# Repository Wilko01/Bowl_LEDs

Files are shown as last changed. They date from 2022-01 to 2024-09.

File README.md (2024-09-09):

# Bowl with LEDS
Control the intensity of the LEDS via a NODEMCU with PWM and add it to Home Assistant

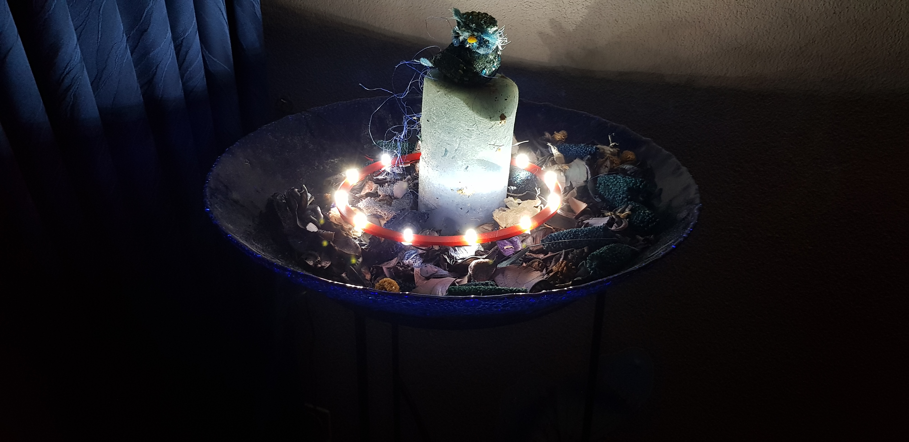
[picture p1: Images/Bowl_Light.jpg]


## Description and operation instructions
12Leds controlled via a dashboard in Home Assistant.

 ## Technical description
Calculate the value of the resistor in relation to the amount of LEDs. In this case 12 LEDs will be used with a forward voltage of 3.2 - 3.4V and a forward current of 20mA. 5V will be used as input as that is minimal required for the NodeMCU and can be powered via an USB charger.
The LEDs will be connected in parallel leaving the voltage over the resistor 5V - 3.3V = 1.7V. Take 12 LEDs multiplied by 20mA = max 240mA. The resistor will then be 1.7V / 240mA = ~8hm. As I did not have a 8 Ohm 0,5W I used a 12 Ohm 0,5W resistor. This also ensures that we are not operating at the edge. A BD139 is used as it needs to deal with 240mA where a BD547C can only deliver 100mA max.
Don't use D4 as it will give issues during boot. Use D5 of the NodeMCU instead.

### Parts
- 1 x NodeMCU

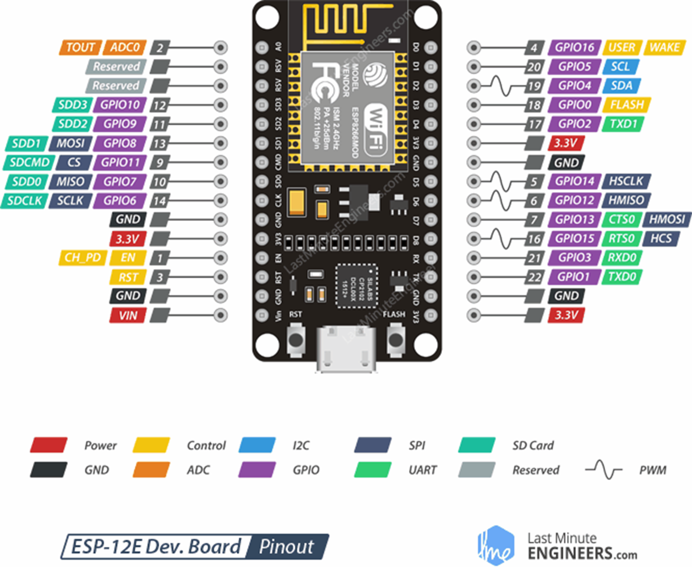
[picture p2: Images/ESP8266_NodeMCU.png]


- 12 x 5mm white led
- 1 x 12 Ohm 0,5W resistor
- 1 x 1k resistor
- 1 x BD139 NPN transistor
- 1 x JST 2.54 2 pin connector

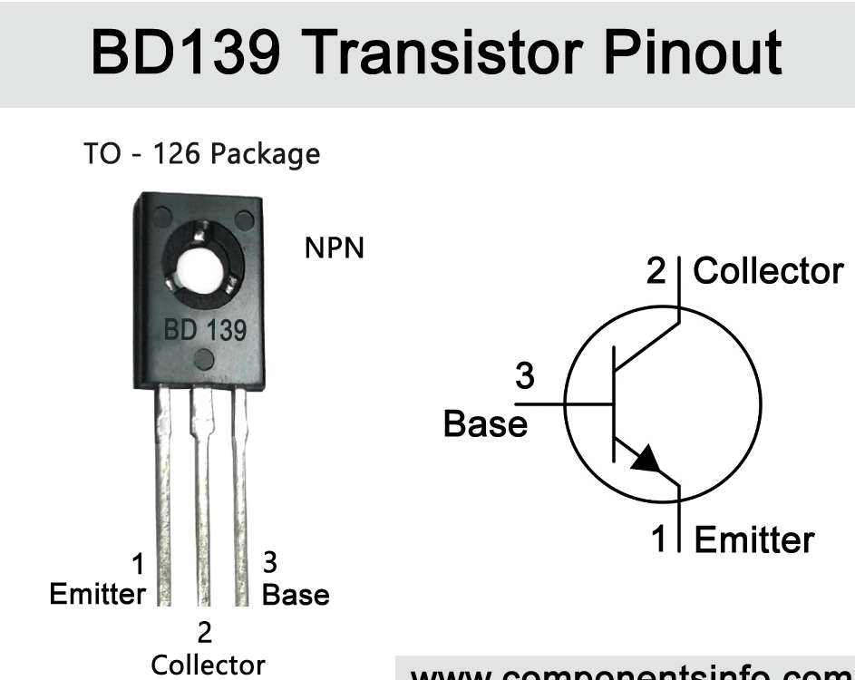
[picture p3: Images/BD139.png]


### Schematic overview
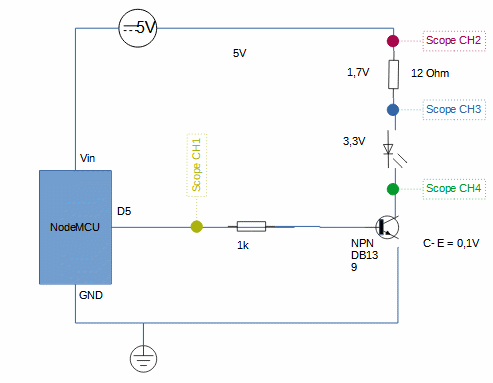
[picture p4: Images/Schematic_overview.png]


### ESPHome installation
See the instructions https://github.com/Wilko01/ESPHome  (not listed here)

### ESPHome Configuration in Home Assistant
Create a new device  with this code:
```
#Running via ESPHOME

#Runs on a NodeMCU

esphome:
  name: bowl-lamp

esp8266:
  board: nodemcuv2

# Enable logging
logger:

# Enable Home Assistant API
api:

ota:
  platform: esphome
  password: "1e7c9c2b1830d88364f40572c813b20f"

wifi:
  ssid: !secret wifi_ssid
  password: !secret wifi_password

  # Enable fallback hotspot (captive portal) in case wifi connection fails
  ap:
    ssid: "Bowl-Leds Fallback Hotspot"
    password: "7lgvJ8aOzZ3w"

captive_portal:

# Add virtual switch to remotely restart the ESP via HA
# https://esphome.io/components/switch/restart
button:
  - platform: restart
    name: "ESP_bowl-leds restart"

#begin code

output:
  - platform: esp8266_pwm
    pin: D5
    frequency: 1000 Hz
    id: pwm_output

fan:
  - platform: speed
    output: pwm_output
    name: "Bowl-Lamp"
#end code
```

### Interface
#### Home Assistant
Home Assistant is connected via the ESPHome integration.

##### card
Create a card in the dashboard of Home Assistant with this code
```
type: entities
entities:
  - fan.bowl_leds
```

### Testing
Turn the led on and off via the card at the dashboard

Scope values when the dim value in Home Assistant is set to 50%

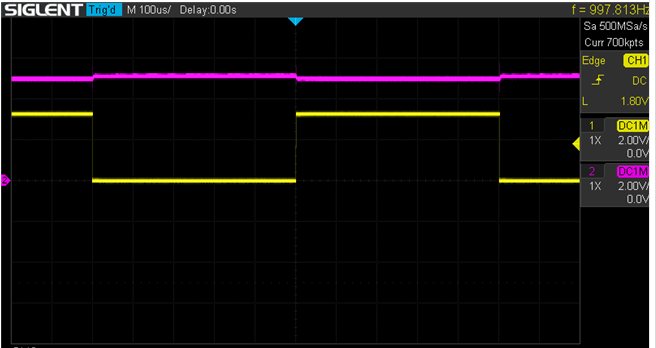
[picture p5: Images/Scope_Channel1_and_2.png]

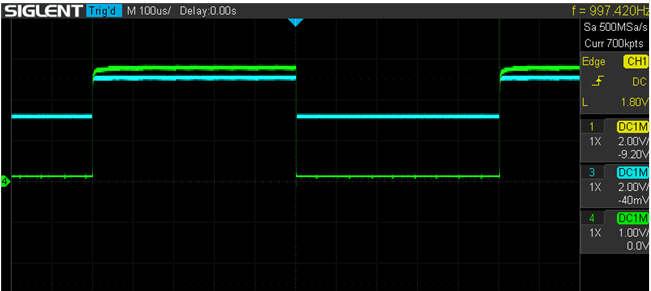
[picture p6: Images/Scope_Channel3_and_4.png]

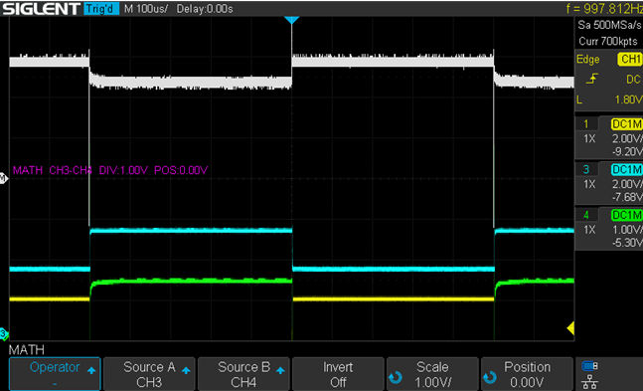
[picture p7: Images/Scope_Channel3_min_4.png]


## 3D printer files
It all started by measuring the air quality when printing, so the 3D printer files must be included in this project:
- [3D files include the Sketchup make file as well as the 3D print files .STL](/3D_Printer_Files)
- [Thingiverse](https://www.thingiverse.com/thing:5224819)

### Problems
During testing with the breadboard, the power used by the LEDs was way below the 20mA. This was mainly due to the bad connections of the breadboard. Once the connections were soldered, the problem was gone and the max current of the LEDs was almost reached.

### Wishlist
..

### Pictures
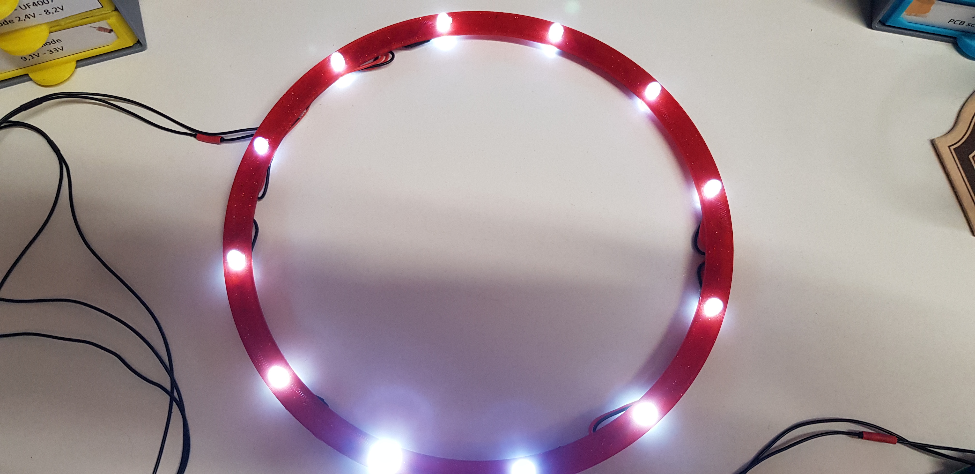
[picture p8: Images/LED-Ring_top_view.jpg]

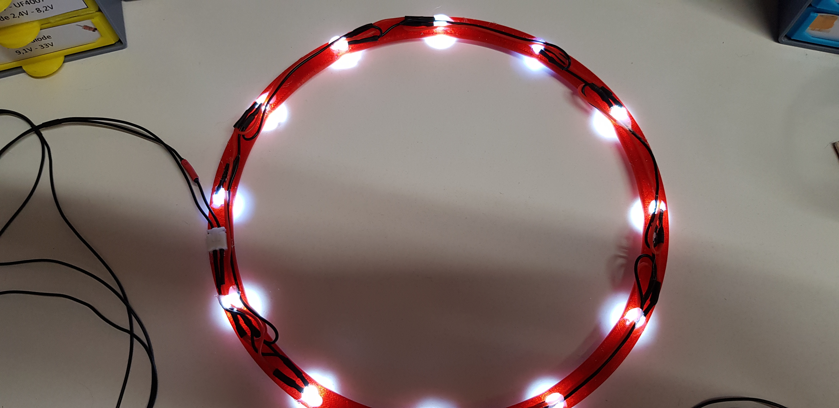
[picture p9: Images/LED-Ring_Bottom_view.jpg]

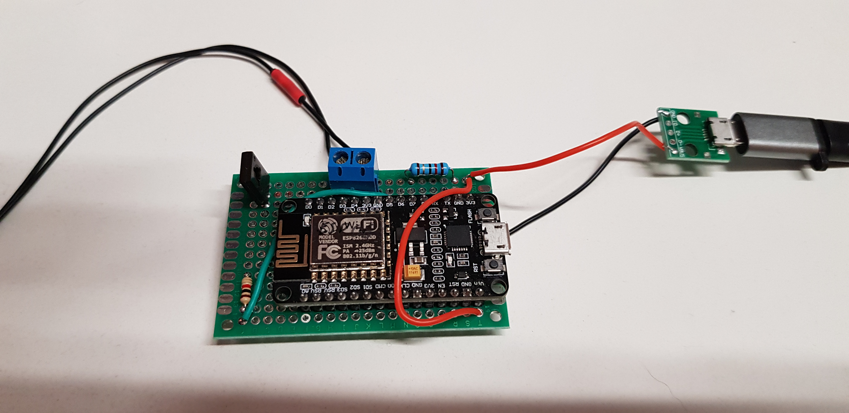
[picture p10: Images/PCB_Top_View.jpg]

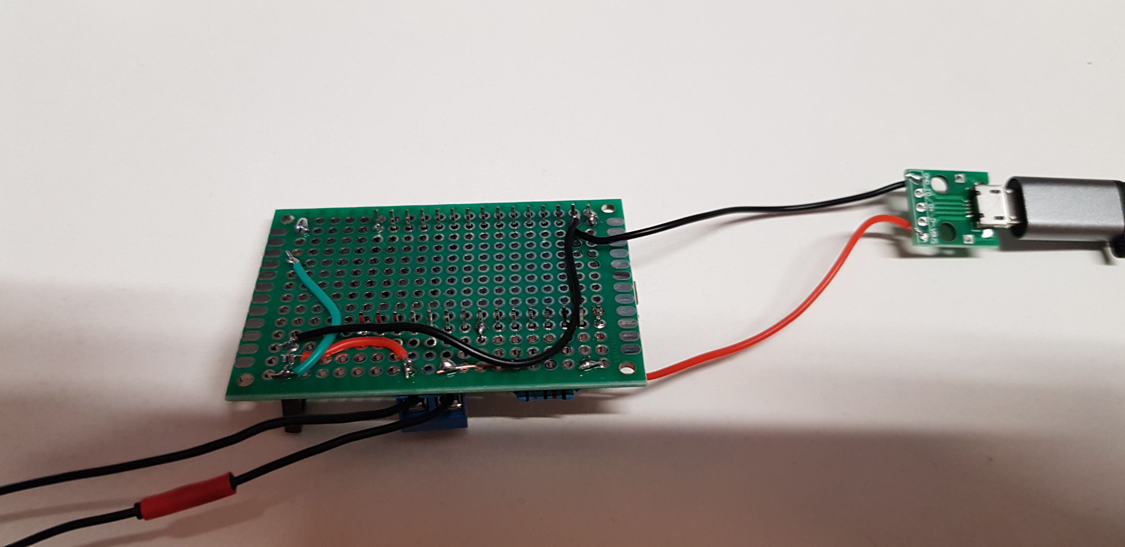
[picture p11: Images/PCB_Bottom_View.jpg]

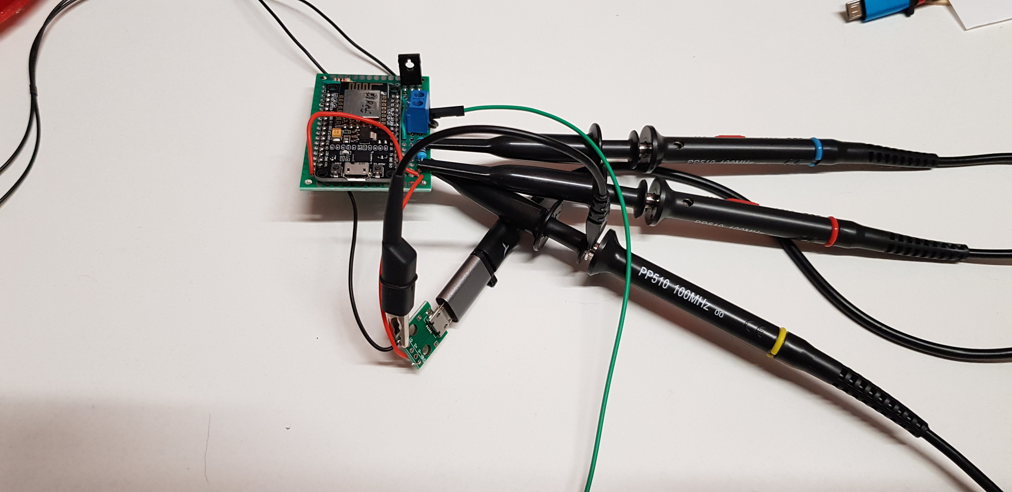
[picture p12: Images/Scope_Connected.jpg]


### Information
- [PNP amplifier circuit](https://circuitdigest.com/electronic-circuits/transistor-as-an-amplifier-circuit)
- [ESPHOME PWM control](https://esphome.io/components/fan/speed.html)

Generic
- [Markdown Cheat Sheet](https://www.markdownguide.org/cheat-sheet/)

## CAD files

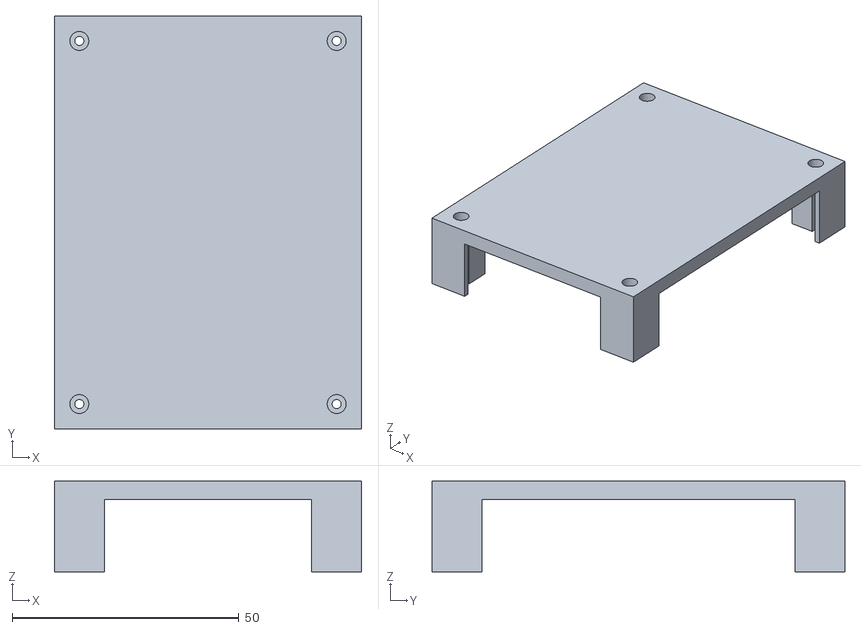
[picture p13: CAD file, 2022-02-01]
3D_Printer_Files/Cover.stl
67.7 x 91.0 x 20.0

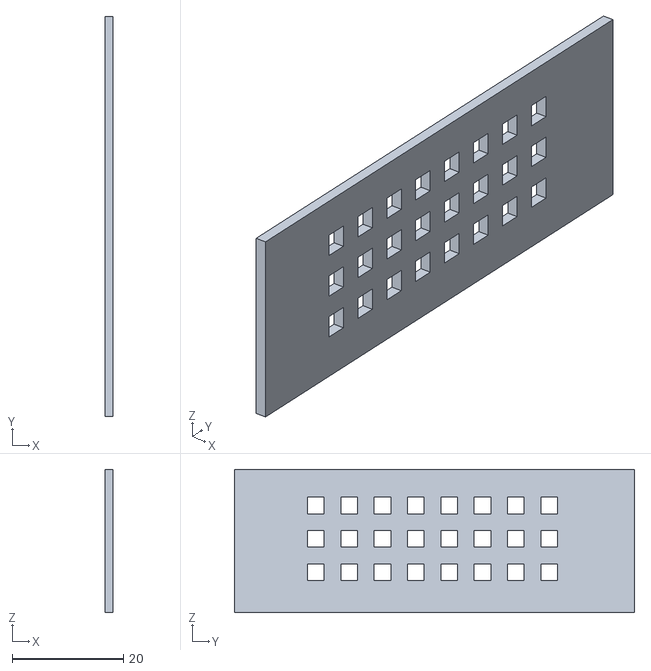
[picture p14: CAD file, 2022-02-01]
3D_Printer_Files/Insert side.stl
1.50 x 72.0 x 25.8

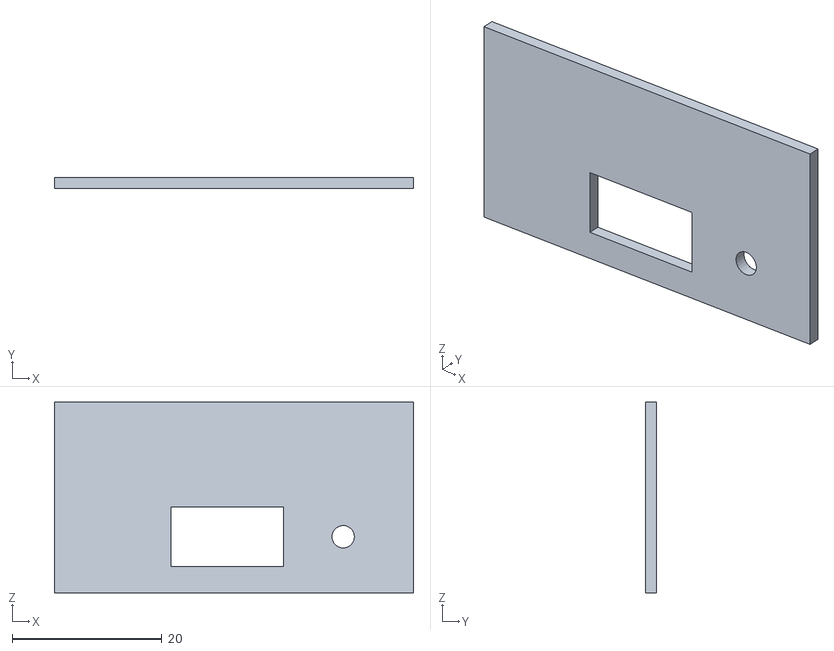
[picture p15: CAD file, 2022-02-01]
3D_Printer_Files/Insert top.stl
48.0 x 1.50 x 25.5

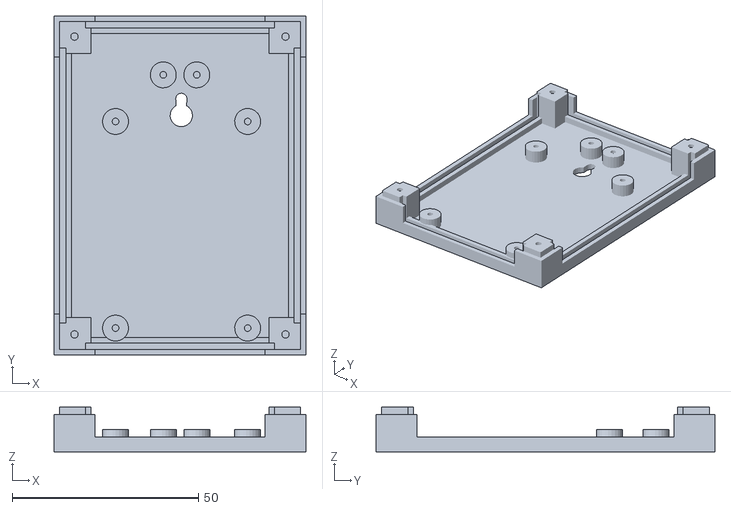
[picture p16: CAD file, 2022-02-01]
3D_Printer_Files/Bottom.stl
67.7 x 91.0 x 12.0

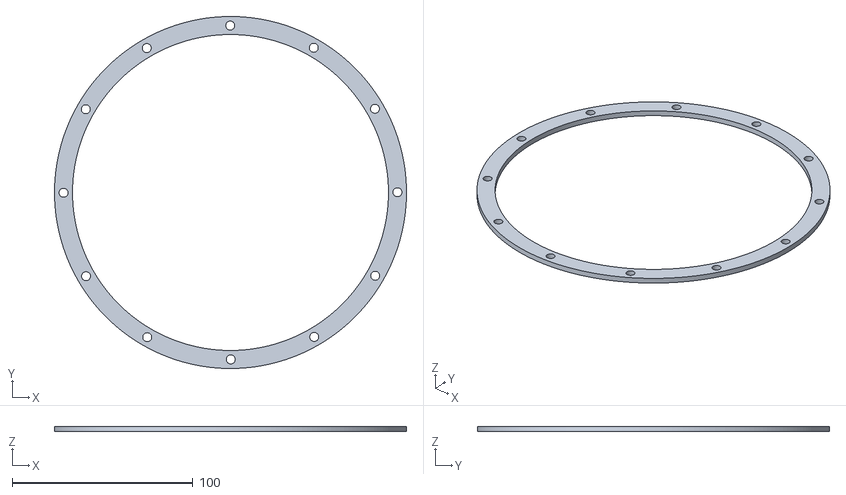
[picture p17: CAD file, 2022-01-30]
3D_Printer_Files/Ring.stl
195.0 x 195.0 x 3.00

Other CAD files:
3D_Printer_Files/Insert bottom.stl
3D_Printer_Files/Bowl_Leds.skp

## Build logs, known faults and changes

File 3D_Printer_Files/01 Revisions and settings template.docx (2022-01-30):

# Print settings:

- Print material: PLA
- Rotation of the objects: No comment.
- Support: No
- Skirt, brim: Skirt.

# Additional instructions

# Materials needed

- PLA
- Screws 3 x 10 mm
- 3 x Bolts M6 x 50
- 3 x Lock ncftg67yuts M6
- 4 x Bolts M3 x 10
- 4 x Nuts M3

# Version 0.2

- First release

# Version 0.1

- First release

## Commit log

2022-01-30 Updated readmy
    [Bowl_Leds.skp, Bowl_Leds.stl]
2022-01-31 Updated 3D printfiles
    [Bottom.stl, Bowl_Leds.skp, Cover.stl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]
2022-02-01 updated 3D files
    [Bottom.stl, Bowl_Leds.skp, Insert bottom.stl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]
2024-09-09 updated led name
